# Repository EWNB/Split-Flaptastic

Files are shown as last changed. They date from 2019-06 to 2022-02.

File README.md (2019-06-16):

# Split-Flaptastic
Various files for making Split-Flap displays

# Files
* Circ/
  * Contains attempts and various circuit designs. [Here are lions](https://en.wikipedia.org/wiki/Here_be_dragons).
* Code/
  * Here lives embedded code for running split-flap devices or parts thereof.
  * RegFlap/ 
    * New Arduino shift register controlled split-flap display program.
  * RegSpinCTRL/
    * Old Arduino shift register controlled split-flap display program.
  * RegSpinFlap/
    * Arduino shift register controlled motor spinner for testing hardware.
* Flaps/
  * Within lies a script most reptilian that creates flap template PDFs.

# Blog
I write about this project on my blog. Search engines don't seem to know that it exists, so here's a link:
https://transistorized-tui.blogspot.com/search/label/Split-Flaptastic
These files on GitHub will likely be ahead of the narative on the blog, as I'm lazy and often prefer to advance the project than bother letting anybody know about it.

# Licence
Not sure yet...

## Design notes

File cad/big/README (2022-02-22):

Designed for 40 flaps.

Curve barrel into a tube with barrel_mount in one end.
Put a wheel on either end with flaps folded towards each other.
Tape flaps onto the barrel.

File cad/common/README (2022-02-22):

Parts use in both big and small designes.

"motor_aligner" fits around the back of the stepper motor
to help hold it in place on the frame.

"tee" slots into the top of the frame and holds the top
edge of the upper flap being displayed.
It will almost certainly need to be trimmed to length.

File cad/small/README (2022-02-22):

Designed for 16 flaps of size 50 mm x 75 mm (both halves together).

Assemble wheel around cardboard toilet paper tube.
Use twist-ties/paperclips and cocktail sticks to hold wheel together.

Use twist-ties/paperclips to hold frame into shape when folded.

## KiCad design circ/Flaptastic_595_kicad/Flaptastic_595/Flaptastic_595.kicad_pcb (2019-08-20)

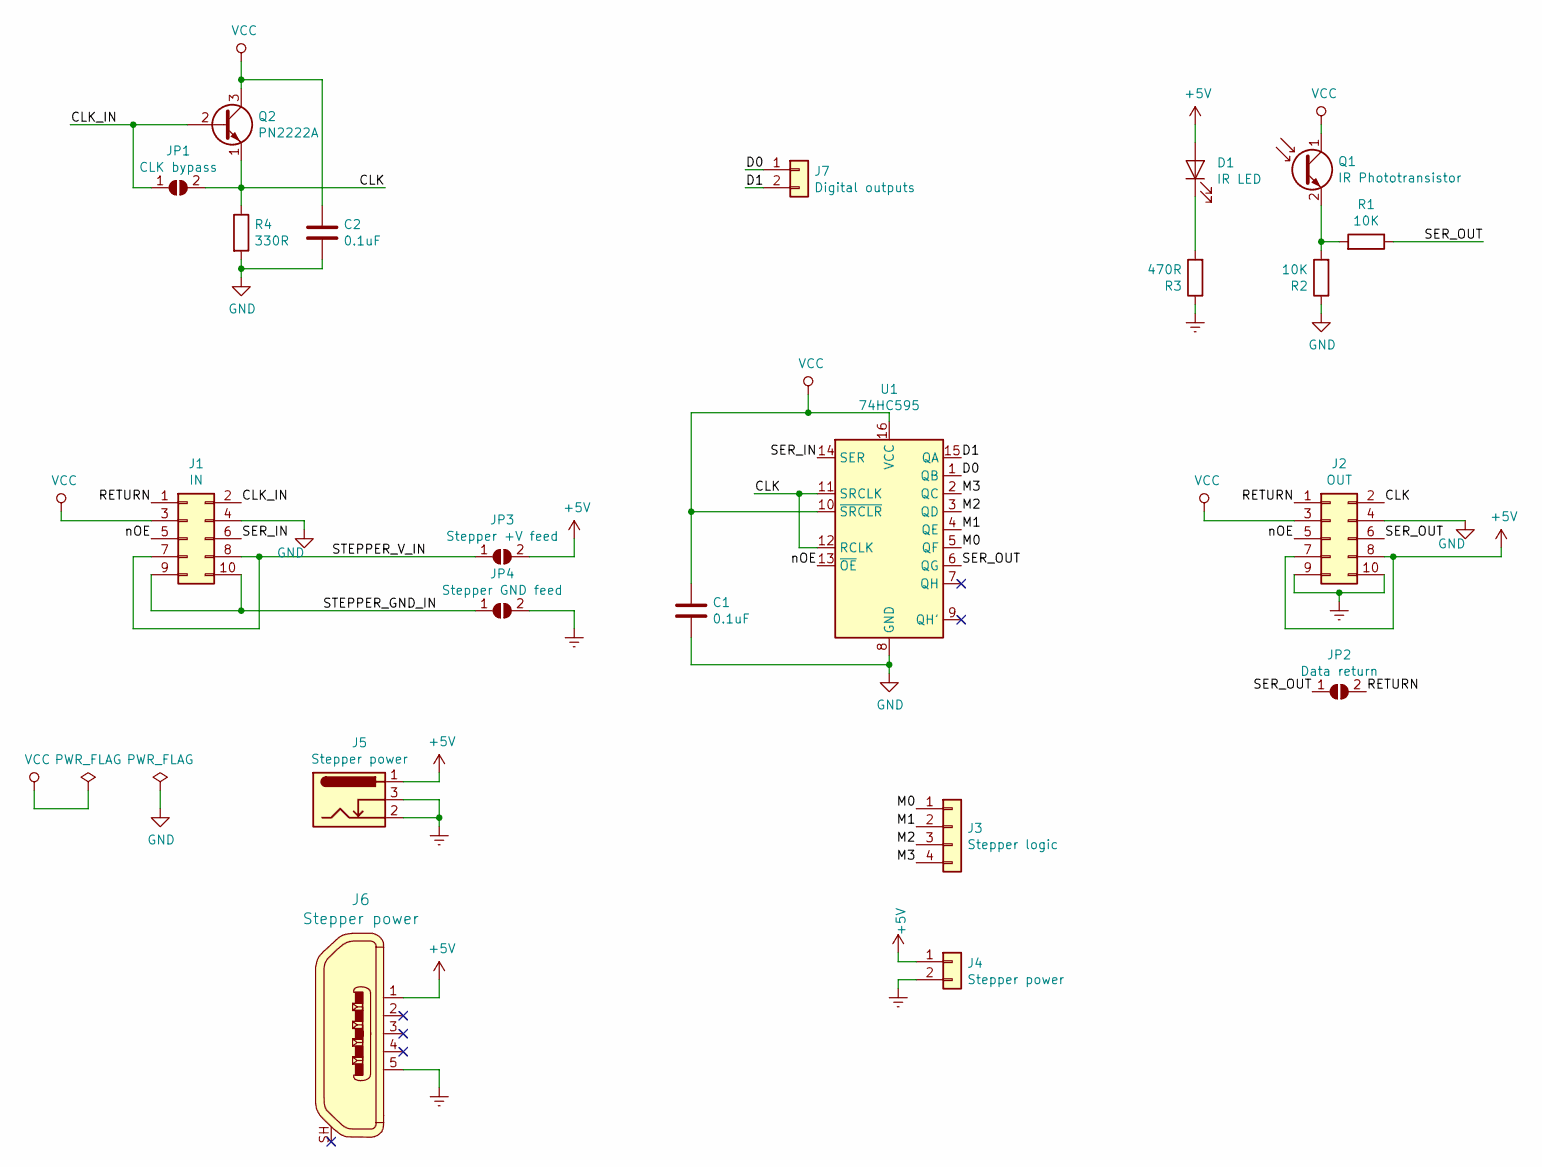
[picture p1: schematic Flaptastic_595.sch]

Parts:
C1, C2: 0.1uF; CAP-PTH-2.54
D1: IR LED; LED_D5.0mm_Clear
J1: IN; IDC-Header_2x05_P2.54mm_Vertical
J2: OUT; IDC-Header_2x05_P2.54mm_Vertical
J3: Stepper logic; PinHeader_1x04_P2.54mm_Vertical
J4: Stepper power; PinHeader_1x02_P2.54mm_Vertical
J5: Stepper power; BarrelJack_CUI_PJ-102AH_Horizontal
J6: Stepper power; USB_Micro_B_Female_10118194-0001LF; MPN 10118194-0001LF; Digi-Key_PN 609-4618-1-ND
J7: Digital outputs; PinHeader_1x02_P2.54mm_Vertical
JP1: CLK bypass; SolderJumper-2_P1.3mm_Open_RoundedPad1.0x1.5mm
JP2: Data return; SolderJumper-2_P1.3mm_Open_RoundedPad1.0x1.5mm
JP3: Stepper +V feed; SolderJumper-2_P1.3mm_Open_RoundedPad1.0x1.5mm
JP4: Stepper GND feed; SolderJumper-2_P1.3mm_Open_RoundedPad1.0x1.5mm
Q1: IR Phototransistor; LED_D5.0mm_IRBlack
Q2: PN2222A; TO-92_Inline
R1, R2: 10K; R_Axial_DIN0204_L3.6mm_D1.6mm_P7.62mm_Horizontal
R3: 470R; R_Axial_DIN0204_L3.6mm_D1.6mm_P7.62mm_Horizontal
R4: 330R; R_Axial_DIN0204_L3.6mm_D1.6mm_P7.62mm_Horizontal
U1: 74HC595; DIP-16_W7.62mm

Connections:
+5V: D1.2 (A), J2.7, J2.8, J4.1, J5.1, J6.1, JP3.2 (B)
/CLK: J2.2, JP1.2 (B), Q2.1 (E), R4.1, U1.11 (SRCLK), U1.12 (RCLK)
/CLK_IN: J1.2, JP1.1 (A), Q2.2 (B)
/D0: J7.1, U1.1 (QB)
/D1: J7.2, U1.15 (QA)
/M0: J3.1, U1.5 (QF)
/M1: J3.2, U1.4 (QE)
/M2: J3.3, U1.3 (QD)
/M3: J3.4, U1.2 (QC)
/RETURN: J1.1, J2.1, JP2.2 (B)
/SER_IN: J1.6, U1.14 (SER)
/SER_OUT: J2.6, JP2.1 (A), R1.1, U1.6 (QG)
/STEPPER_GND_IN: J1.9, J1.10, JP4.1 (A)
/STEPPER_V_IN: J1.7, J1.8, JP3.1 (A)
/nOE: J1.5, J2.5, U1.13 (~OE)
Earth: J2.9, J2.10, J4.2, J5.2, J5.3, J6.5, JP4.2 (B), R3.1
GND: C1.2, C2.2, J1.4, J2.4, R2.1, R4.2, U1.8 (GND)
unnamed: D1.1 (K), R3.2
unnamed: Q1.2 (E), R1.2, R2.2
VCC: C1.1, C2.1, J1.3, J2.3, Q1.1 (C), Q2.3 (C), U1.10 (~SRCLR), U1.16 (VCC)

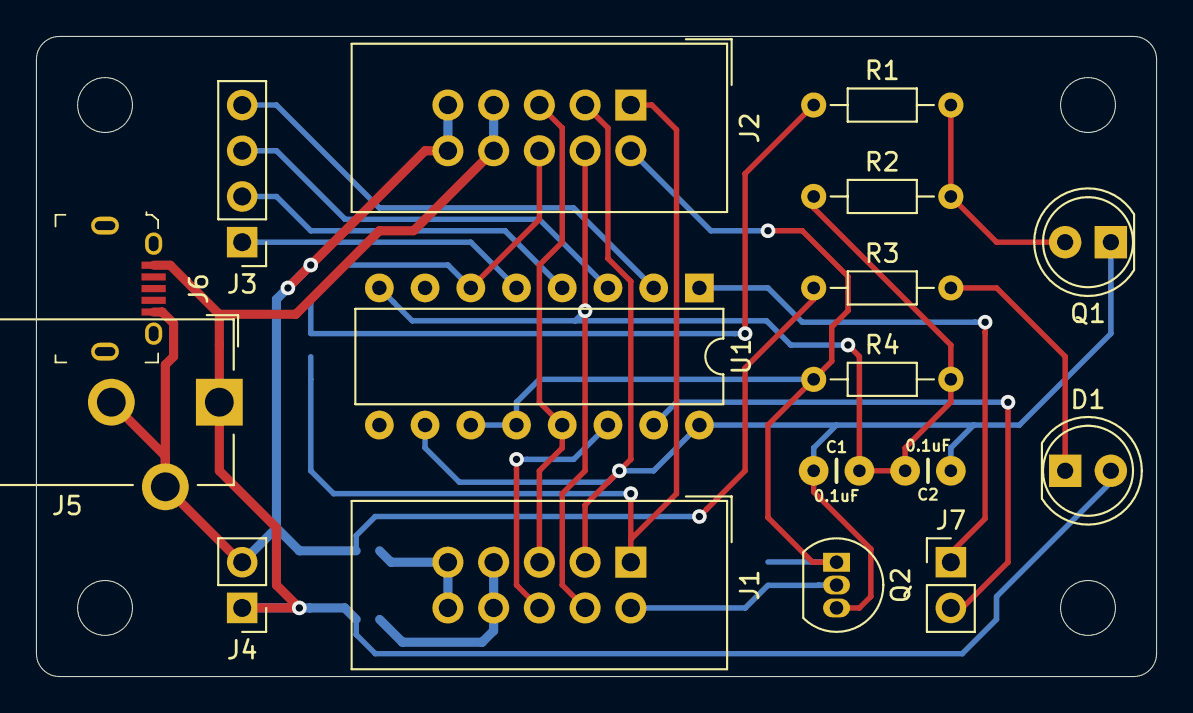
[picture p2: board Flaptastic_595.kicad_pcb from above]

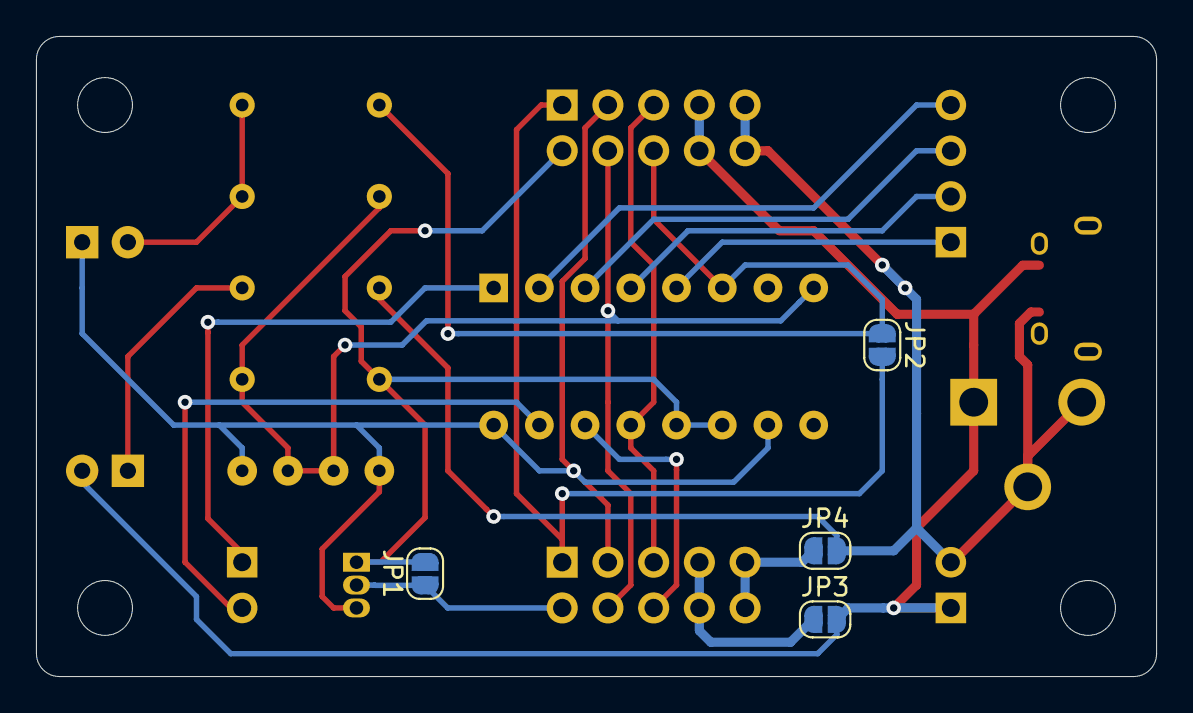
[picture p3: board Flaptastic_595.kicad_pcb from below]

Board: 2 copper layers, 62.2 x 35.6 mm, 21 parts (4 on the bottom side), 20 nets.

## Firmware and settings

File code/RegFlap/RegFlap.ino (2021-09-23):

// Split-Flap display library testing program
// Elliot Baptist 2019/06/16

// Includes
#include <SPI.h>
#include "flaptastic.h"

// Constants
const int N_OE_PIN = 10;
const int CE_PIN = 9;
const int STEPPER_STEP_PERIOD_US = 2400;

// Functions
int char_to_flap(char ch) {
  if ('0' <= ch && ch <= '9') {
    return ch - '0';
  }
  ch = toupper(ch);
  if ('A' <= ch && ch <= 'F') {
    return ch - 'A' + 0xA;
  }
  return -1;
}

// Globals
EWNB::Flaptastic disp;
unsigned long last_time;
unsigned long last_active;
char ch, flap;
bool flash;

// Setup
void setup() {
  // Serial setup
  Serial.begin(230400);
  Serial.println(F("RegFlap EWNB::Flaptastic test program booting"));

  // Split-flap display 'chip enable' (CLK pass enable) setup
  pinMode(CE_PIN, OUTPUT);
  digitalWrite(CE_PIN, LOW); // LOW == disable CLK to split-flap display

  // SPI setup
  SPI.begin();
  SPI.beginTransaction(SPISettings(8000000, LSBFIRST, SPI_MODE0));

  // Split-flap display global setup
  disp.init({N_OE_PIN}, &SPI);
  
  // Split-flap display unit setup
  EWNB::Flaptastic::unit_cfg_t unit_cfg;
  unit_cfg.motor_level = 1;
  unit_cfg.home_rising = false;
  unit_cfg.thresh = 0b11110000;
  unit_cfg.steps = 2048;
  unit_cfg.dir = 1;
  unit_cfg.flaps = 16;
  unit_cfg.offset = unit_cfg.steps / (unit_cfg.flaps * 2) - 5;
  unit_cfg.tolerance = 100;
  disp.addUnit(unit_cfg);

  // Timer interrupt setup
  noInterrupts(); // global interrupt disable while configuring
  TCCR2A = 0b00000010; // CTC (counter clear) mode
  TCCR2B = 0b00000110; // clk/256
  OCR2A = STEPPER_STEP_PERIOD_US/(256/16); // period
  TCNT2 = 0; // reset count
  TIMSK2 = 0b00000010; // interrupt on OCR2A compare match
  interrupts(); // renable interrupts

    // Home all units
  while (!disp.allDone()) ;

  // Initialise time variables
  last_time = millis();
  last_active = millis();
}

// Timer ISR 
ISR(TIMER2_COMPA_vect) {
//  unsigned long start = micros();
  digitalWrite(CE_PIN, HIGH);
  disp.step();
  digitalWrite(CE_PIN, LOW);
//  Serial.println(micros() - start);
}

// Loop
void loop() {
  // Set things for split-flap display to display
  if (1000 < millis() - last_time) {
    flap = -1;
    ch = Serial.read();
    if (ch != -1) {
      // user message
      flap = char_to_flap(ch);
      last_active = millis();
    } else if (last_active + 10000 < millis()) {
      // counting mode
      flap = (millis() / 1000) % 0x10;
    }
    last_time = millis();
    if (flap != -1) {
      disp.setFlap(0, flap);
    }
  }

  // Flash LEDs attached to display unit 0
  if (bool(millis()&(1<<8)) != flash) {
    flash = !flash;
    disp.setOut(0, 0, flash);
    disp.setOut(0, 1, !flash);
  }

  // Enable timer interrupt only when required, 'cause why not
  if (disp.allDone() && TIMSK2 & 0b00000010) {
    noInterrupts(); // global interrupt disable
    TIMSK2 &= ~0b00000010; // disable interrupt
    interrupts(); // renable global interrupts
  } else if (!disp.allDone() && !(TIMSK2 & 0b00000010)) {
    noInterrupts(); // global interrupt disable
    TIMSK2 |= 0b00000010; // enable interrupt
    interrupts(); // renable global interrupts
  }
  
}

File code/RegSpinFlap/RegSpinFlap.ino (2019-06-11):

// Include
#include <SPI.h>
#include <Print.h>

// Constants
const int SREG_nOE_PIN = 10;


const int SREG_NUM_BITS = 8;
const int SREG_NUM_REGS = 3;

const bool STEPPER_LEVEL[SREG_NUM_REGS] = {1,1,1};
const bool STEPPER_DIR[SREG_NUM_REGS] = {0,1,0};

// Globals
byte currentStepperState[SREG_NUM_REGS];
bool rotateStepper[SREG_NUM_REGS] = {0,0,0};

// Functions

void setRotation(int stepper, bool rotate) {
  rotateStepper[stepper] = rotate;
}

void doStep() {
  for (int i = 0; i < SREG_NUM_REGS; i++) {
    if (rotateStepper[i]) {
      if (STEPPER_DIR[i])
        currentStepperState[i] = ((currentStepperState[i]&0x07) << 1) | ((currentStepperState[i]&0x08) >> 3);
      else
        currentStepperState[i] = ((currentStepperState[i]&0x0E) >> 1) | ((currentStepperState[i]&0x01) << 3);
    }
  }

  byte shift_data[SREG_NUM_REGS];
  digitalWrite(SREG_nOE_PIN, HIGH);
  //delay(1);
  //shift_data[0] = SPI.transfer(0);
  SPI.transfer(0);

  digitalWrite(SREG_nOE_PIN, LOW);
  for (int i=0; i<SREG_NUM_REGS; i++) {
    byte read_val = SPI.transfer(currentStepperState[i]<<2);
    //if (i<SREG_NUM_REGS-1) shift_data[i+1] = read_val;
    shift_data[i] = read_val;

  }
  for (int i=0; i<SREG_NUM_REGS; i++) {
    Serial.print(shift_data[i], BIN);
    if (i<SREG_NUM_REGS-1) Serial.print(',');
  }
  Serial.println();
}

// Setup
void setup() {
  Serial.begin(230400);
  Serial.println("Booting RegSpinFlap");

  SPI.begin();
  SPI.beginTransaction(SPISettings(8000000, LSBFIRST, SPI_MODE0));

  pinMode(SREG_nOE_PIN, OUTPUT);

  digitalWrite(SREG_nOE_PIN, LOW);

  for (int i = 0; i < SREG_NUM_REGS; i++) {
    currentStepperState[i] = STEPPER_LEVEL[i] ? 0x01 : 0x0E;
    setRotation(i,1);
  }
}

void loop() {
  for (int i = 0; i < 513*4; i++){
    doStep();
    delayMicroseconds(2000);
  }
}

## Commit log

2019-04-13 Interrupt timing and semi-functional target setting
2019-04-13 Fixed target find, homes every rev
    [RegSpinCTRL.ino, RegSpinFlap.ino, RegSplitFlap.cpp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]
2019-04-13 [circ] Fritzing 595 circ start
    [Split-flap_595.fzz, Split-flap_595a.fzz]
2019-04-16 [circ] Reduce to one 595 circuit, tweaks from getting it running
    [Split-flap_595.fzz, Split-flap_595a.fzz]
2019-05-28 [tidy] Lower case directory names
2019-06-13 [circ] Add cap to logic power
    [Split-flap_595.fzz]
2019-08-06 Draft PCB in KiCAD
    [Flaptastic_595.kicad_pcb, Flaptastic_595.sch]
2019-08-20 Worked on PCB, rm bak files
    [Flaptastic_595.kicad_pcb, Flaptastic_595.sch]
2019-08-20 Ignore KiCad temp files
2019-09-24 Draft laser cut designs
2019-10-01 Worked on wheel for laser cut
2019-10-01 Add Arduino Makefile
2019-10-08 Refined laser-cut designs
2019-10-15 Further laser-cut improvements
2021-10-07 Draft smaller wheel and frame
2022-02-08 Tweak cad designs after prototype
2022-02-22 Add cad doc, flaps.py classes
2022-03-08 WIP calculate frame size
    [frame_calculations.ods]
2022-03-15 Refined frame calculations and design
    [frame_calculations.ods]
2022-03-22 Tweak frame some more
    [frame_calculations.ods]
2022-04-12 Further flaps.py refinements
    Added shebang, module docstring, more default args, added unicode
    symbols to the example, removed old 'space' flap insertion, added
    comments, added check of provided image paths.
2022-05-24 Update frame calc, part-update svg
    [frame_calculations.ods]
2022-06-07 Started on frame diagram
